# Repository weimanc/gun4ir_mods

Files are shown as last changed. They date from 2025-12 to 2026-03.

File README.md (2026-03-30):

# My GUN4IR blog and mods

## Table of Contents

- [Trigger switch and Recoil](#trigger-switch-and-recoil)
- [Wiimote Sensor and Lens](#wiimote-sensor-and-lens)
- [USB Hub and Power](#usb-hub-and-power)
  - [USB over CAT](#usb-over-cat)
  - [Custom hub](#custom-hub)
    - [RJ45 Pinout](#rj45-pinout)
  - [GUN4IR logo](#gun4ir-logo)
  - [Future ideas](#future-ideas)
- [Bill of materials](#bill-of-materials)
- [Credits and references](#credits-and-references)

I've modified two GunCon1 controllers for my GUN4IR build.

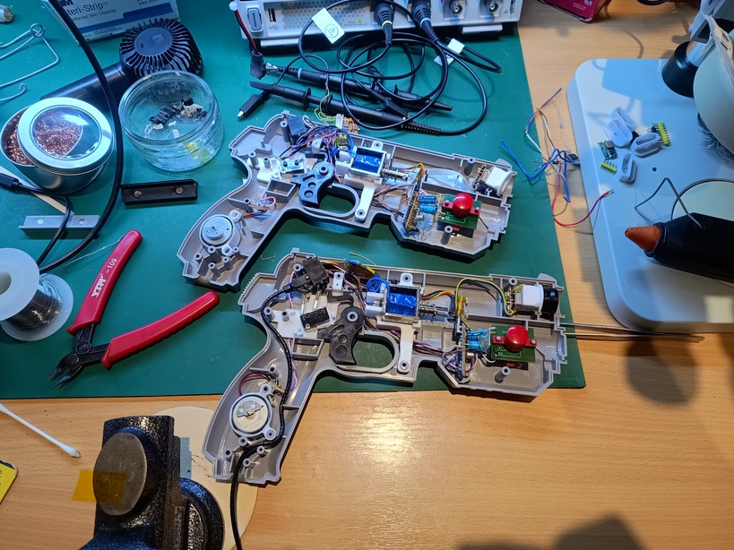
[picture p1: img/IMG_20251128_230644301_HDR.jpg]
My two GunCon1 controllers


# Trigger switch and Recoil

TODO

# Wiimote Sensor and Lens

TODO

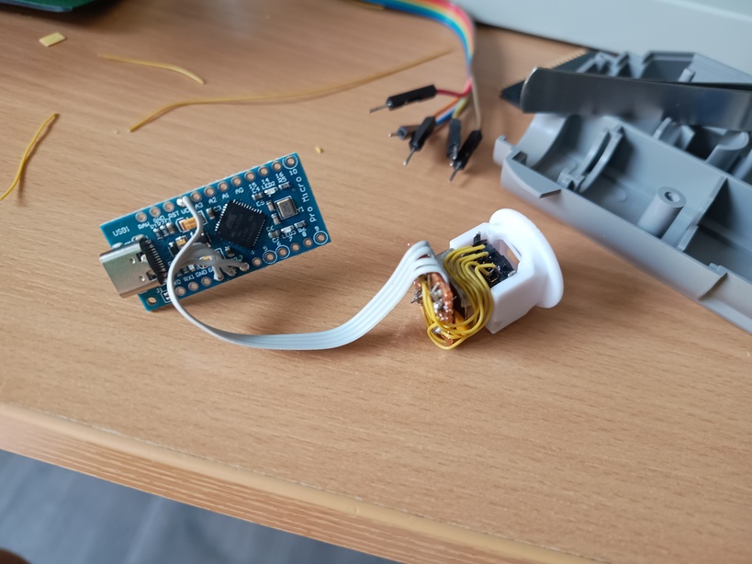
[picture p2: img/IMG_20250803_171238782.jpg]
Extracted Wiimote sensor on a breakout board


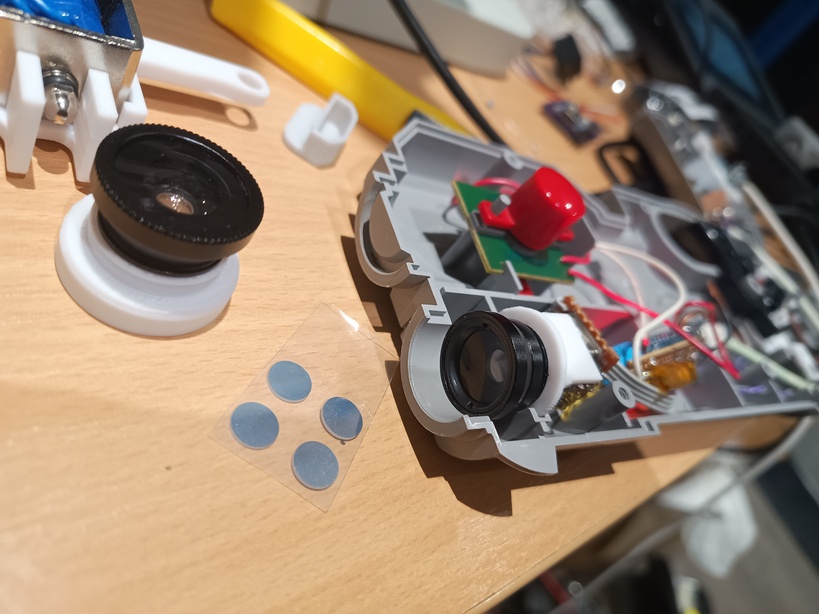
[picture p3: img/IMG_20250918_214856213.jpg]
IR filter and micro lens squeezed in the housing


# USB Hub and Power

I didn't like the idea of having two wires coming out of the GunCon1 — one for USB and one for power. I wondered if I could use an Ethernet cable for the controller wire so I could swap cables in the future. Ethernet cable has 8 wires: 4 for USB and 4 for power, which should be sufficient.

With the 24V external power supply I can power other devices. There are USB power modules that support Quick Charge and USB Power Delivery (USB‑PD). This could be used to power a device such as the MiSTer FPGA.
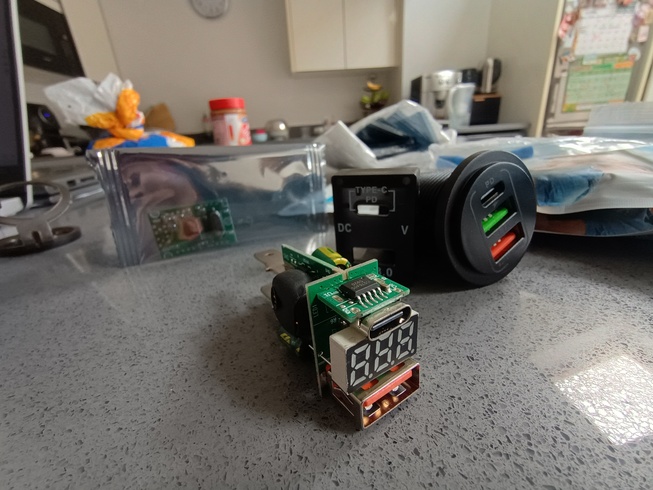
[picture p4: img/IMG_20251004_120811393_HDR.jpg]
USB-PD power module


## USB over CAT

I've read that USB cables are recommended up to 1.2 meters. I had a bad experience extending USB cables for a keyboard and mouse setup, which made me cautious.
I needed to check whether USB would work over Ethernet cable. I made a small prototype and, to my surprise, it did work — even with a 5 m cable!

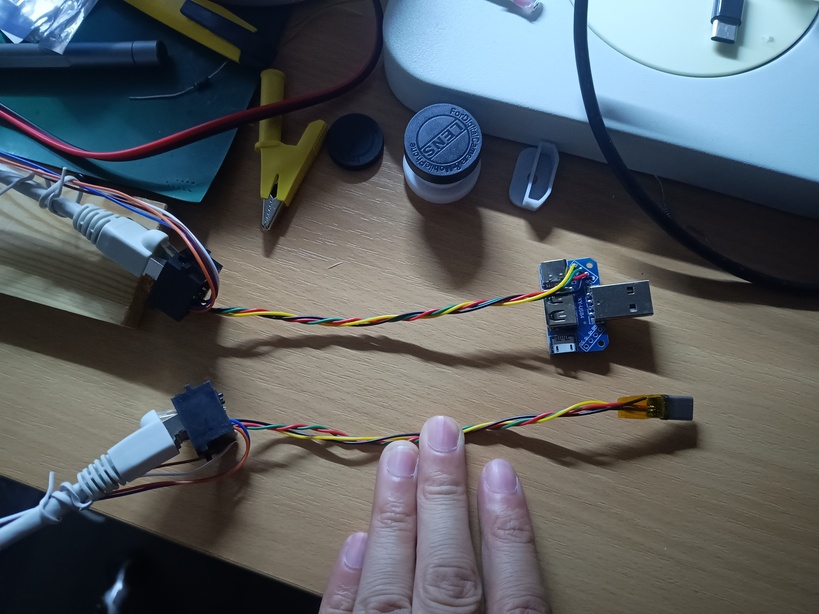
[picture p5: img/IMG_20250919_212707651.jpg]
Testing USB over CAT

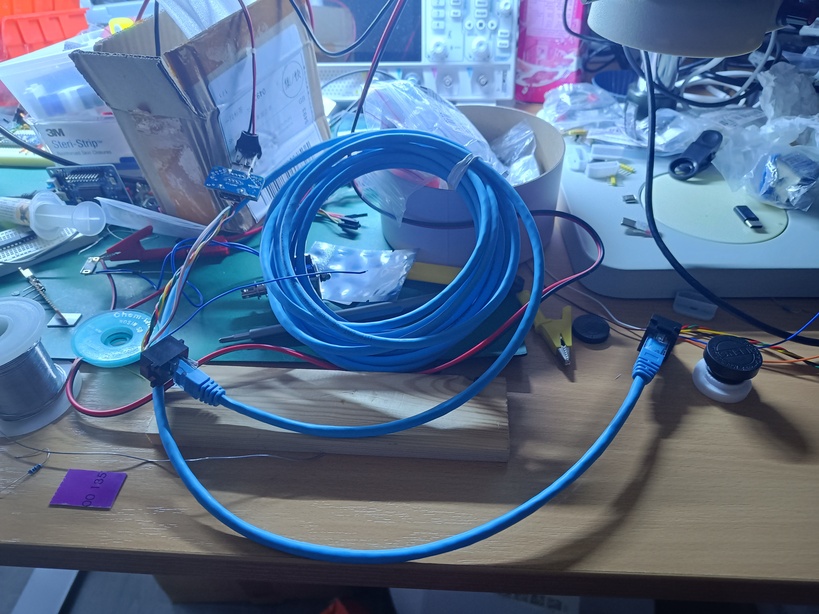
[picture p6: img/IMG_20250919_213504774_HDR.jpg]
Testing with 5 meter Ethernet cable


## Custom hub

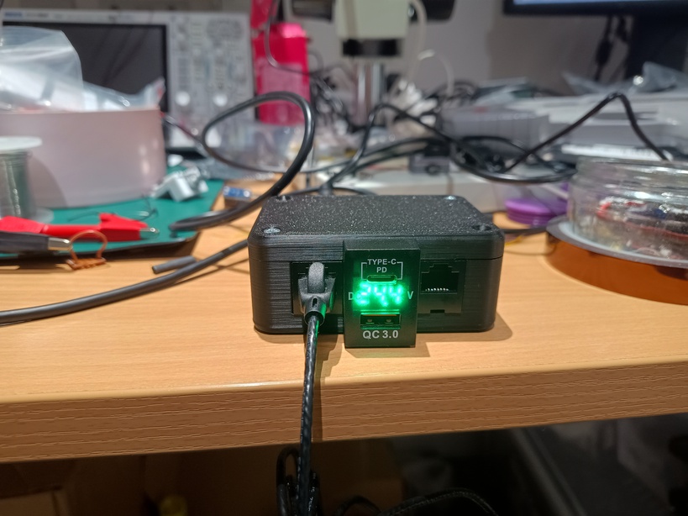
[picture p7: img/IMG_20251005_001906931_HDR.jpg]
GUN4IR custom hub


I want to keep the overall wiring tidy and neat. My plan was to create a custom box to house the USB hub and bring 24V power in to feed the GunCons. On AliExpress I found a PCB-only 4-port USB hub and a 24V power brick, and a 24V-to-USB‑PD power module that could also power my MiSTer FPGA box.

Using Onshape, I've created a simple box with cutouts:

- 2x RJ45 ports
- USB‑PD power out
- USB‑B towards the host
- 24V barrel jack power in
- Power switch

To my surprise, I got all dimensions right, I didn't need to reprint. Some of the connects (DC and USB-B) have a very tight fit.
Wiring is straightforward. I did, however, burn out a USB hub due to incorrect USB wiring. This was caused by a Google search that returned an image with the wrong USB‑B pinout.

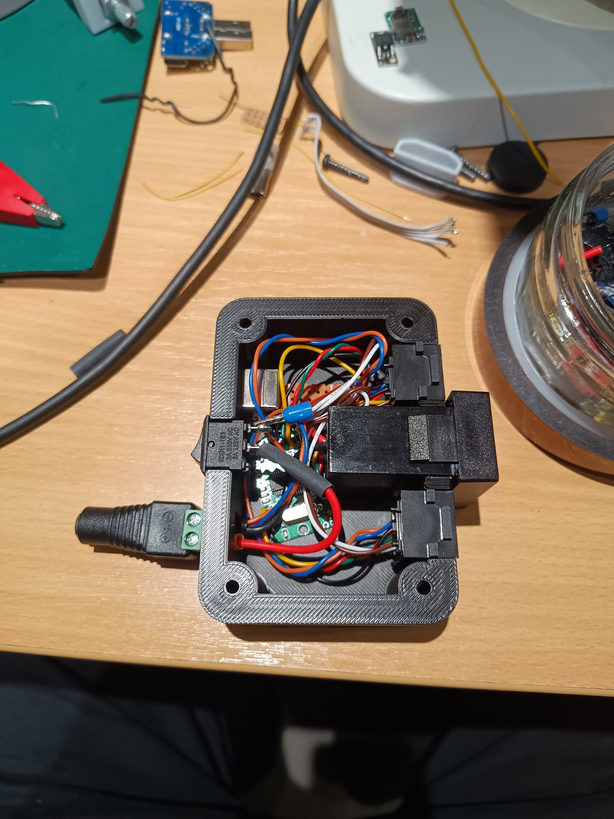
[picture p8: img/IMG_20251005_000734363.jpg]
Wiring inside my custom hub


### RJ45 Pinout

Look for "641D 8P" in AliExpress. This is a nice wired modular jack 8P8C assembly, compatible to accept network etherne wires. The twisted pairs are being use hoping that the USB datapair will benefit from this. The 24V is making use of 4 wires. This is the pinout used:

| 641D 8P Connector | RJ45 Pin | RJ45 T-568B  | Function |
| --- | --- | --- | --- |
| Yellow | 6 | Green | USB VCC |
| Black | 3 | Green/White  | USB GND |
| Red | 4 | Blue | USB D+ |
| Green | 5 | Blue/White | USB D- |
| White | 8 | Brown | Solenoid 24V |
| Brown | 7 | Brown/White  | Solenoid 24V |
| Orange | 2 | Orange | Solenoid 0V  |
| Blue | 1 | Orange/White | Solenoid 0V  |

## GUN4IR logo

The hub looked boring and needed some flare. I thought the GUN4IR logo would look awesome and asked JayBee for his blessing. He provided me a STEP file, which helped the CAD work.

[click for printing instructions](INSTRUCTIONS_LOGO.md)

## Future ideas

There are a few ideas I have for this hub that would be cool. The USB hub is a 4 port hub. So with 2 GunCon ports, I have two unused ports:

- expose unused USB ports
- built-in USB storage
- a gamepad as the case top — this could make a really cute controller!

# Bill of materials

# Credits and references

## Onshape

[My GUN4IR Onshape project](https://cad.onshape.com/documents/60f3889d38b5e0568d106ee2/w/f5cb8cd99e0bbe5bb5cbe4ad/e/dea12f17ca6bb715148ab42e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)

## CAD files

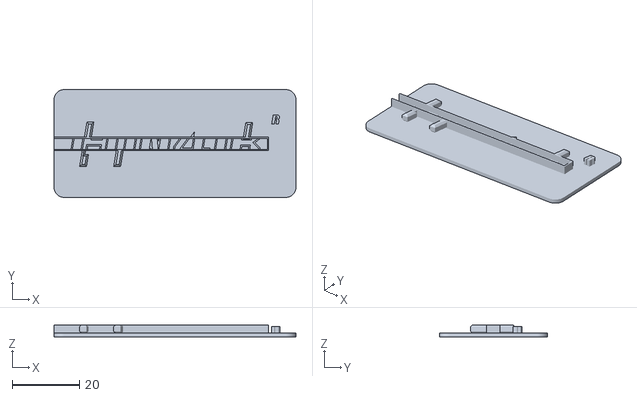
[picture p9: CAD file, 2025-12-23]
stl/hub24v_case - base.stl
71.8 x 32.0 x 3.70

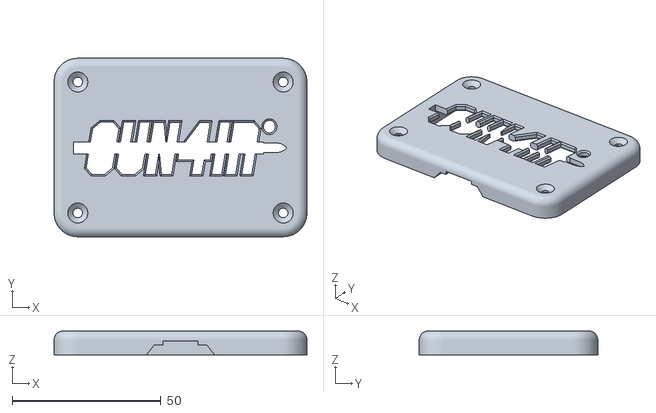
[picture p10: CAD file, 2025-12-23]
stl/hub24v_case - cover.stl
85.0 x 60.0 x 8.05

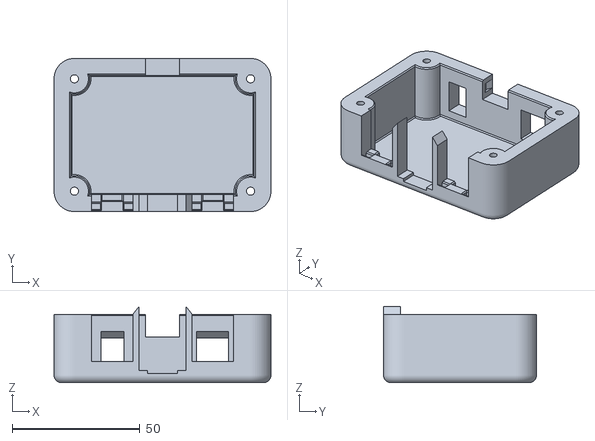
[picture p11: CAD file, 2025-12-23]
stl/hub24v_case - case.stl
85.0 x 60.0 x 29.9

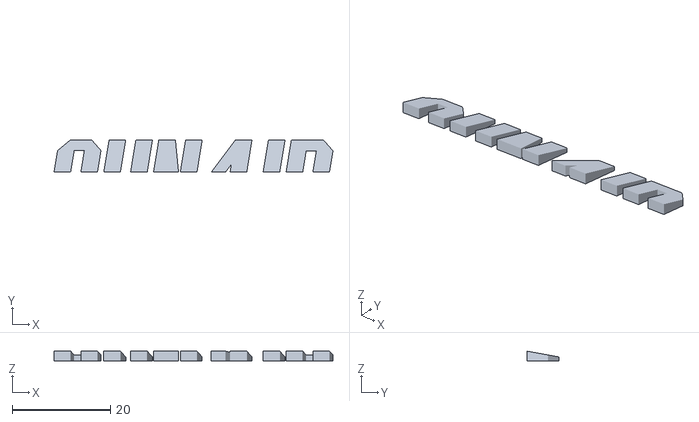
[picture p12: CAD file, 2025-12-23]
stl/hub24v_case - letters upper.stl
56.7 x 6.59 x 2.00

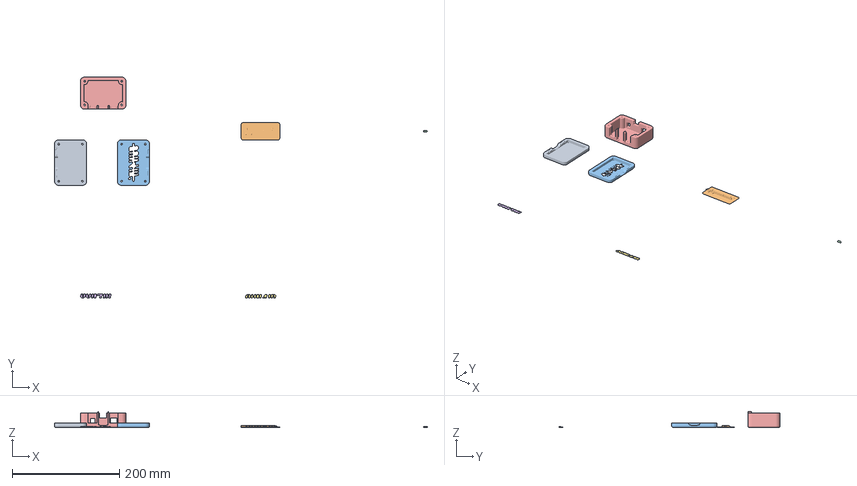
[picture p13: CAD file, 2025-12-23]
stl/hub24v_case.3mf
694.9 x 411.7 x 29.9 mm
hub24v_case - Part 1.stl
hub24v_case - base.stl
hub24v_case - cover.stl
hub24v_case - bullet.stl
hub24v_case - Part 2.stl
hub24v_case - letters lower.stl
hub24v_case - letters upper.stl

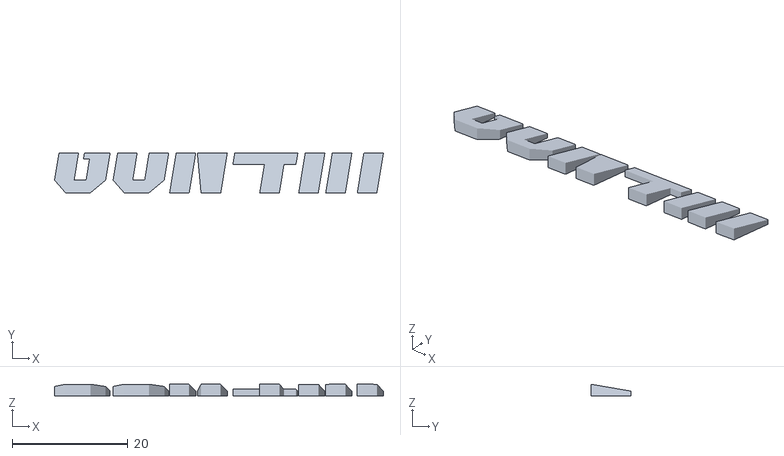
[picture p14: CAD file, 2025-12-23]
stl/hub24v_case - letters lower.stl
56.8 x 6.98 x 2.00

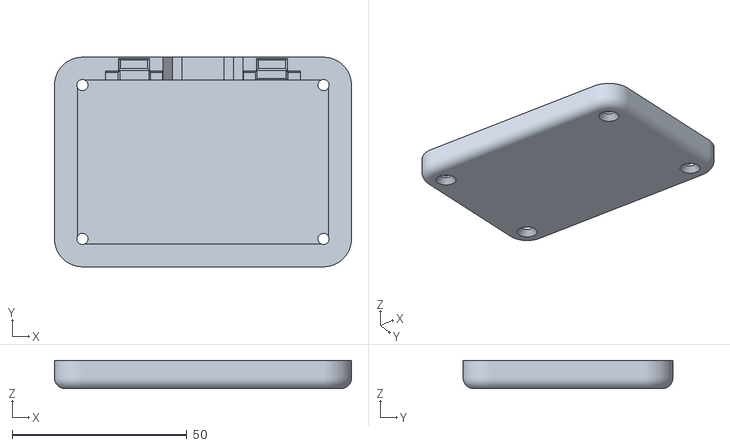
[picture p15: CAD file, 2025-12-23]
stl/hub24v_case - cover_blank.stl
85.0 x 60.0 x 8.05

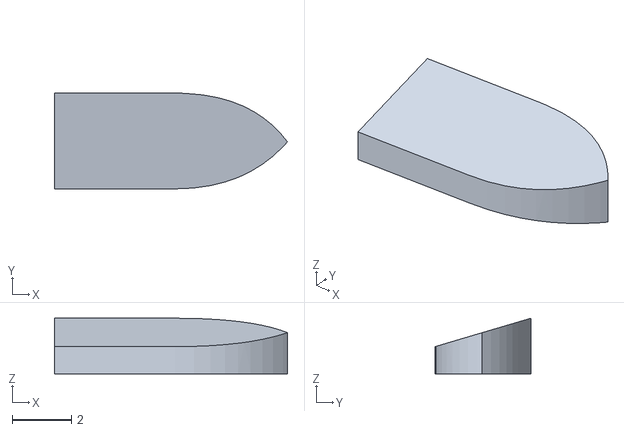
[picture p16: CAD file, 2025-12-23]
stl/hub24v_case - bullet.stl
7.89 x 3.24 x 1.88

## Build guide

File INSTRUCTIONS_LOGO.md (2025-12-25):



# GUN4IR Logo

3D printing is amazing — you can print custom cases with ease. I have a Bambu P1S with AMS. I don't do many multi‑colour prints because the purging (printer "poop") is very wasteful. I like to challenge myself by limiting to a maximum of one colour swap per print. I try to skip or reduce purging and experiment with mixing two colours so the blend becomes a feature.

The GUN4IR logo uses four colours: red, blue, white, and black. The logo features colour gradients in discrete steps, which reminded me of the stair-step effect when printing a slope (z-height relative to layer thickness). The idea is to use the more translucent colour to build up the slope and create the colour change.

I count five bands for the colour gradient. Using a layer height of 0.2 mm, the slope height is (5 + 1) * 0.2 = 1.2 mm — the extra +1 is a margin to allow for slicer behaviour.

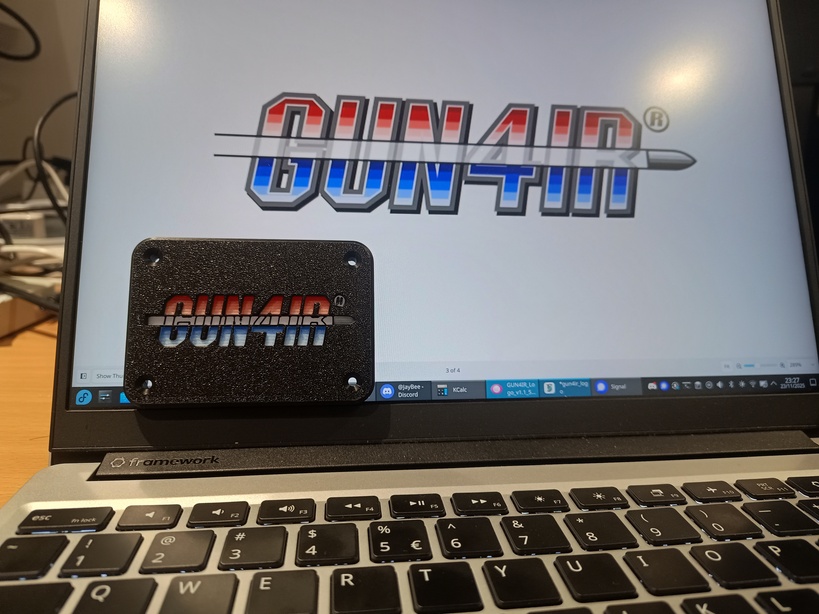
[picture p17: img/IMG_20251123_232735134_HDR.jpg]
Printed case top vs GUN4IR logo


# Printing instructions

Global settings

- Layer height: 0.2 mm
- Detect thin walls
- Disable prime tower

The GUN4IR logo consists of five parts.

| Part | Colour 1 | Colour 2 | Swap layer | Flushing volume multiplier | Brim |
| --- | --- | --- | --- | --- | ---- |
| cover | black | | | | |
| base | white | black | 7 | 0.70 | |
| bullet | black | white | 6 | 0.70 | 3 mm |
| letters lower  | blue | white | 5 | 0.15 | 3 mm |
| letters upper  | red | white | 5 | 0.15 | 3 mm |

For the red→white and blue→white transitions, you can get away with a reduced flushing volume. For black↔white you do need to purge the extruder properly. I set the global multiplier to 0.15 but restored the black↔white parameters to their default values. In theory you could use these flushing volume settings:

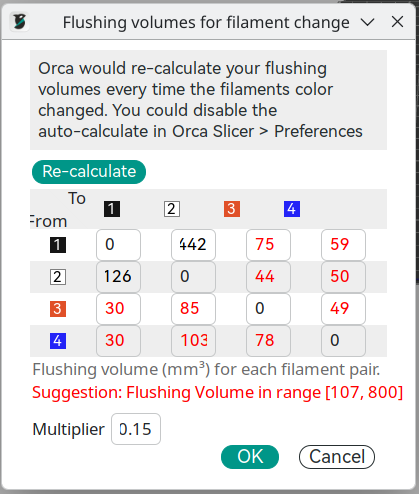
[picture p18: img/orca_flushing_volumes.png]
Flushing volume settings in OrcaSlicer


# Assembly instructions

The bullet and letters are printed with a brim. This helps keep the letter parts together and also aids alignment with the base. Some trimming of the brim is needed to make the letters fit.

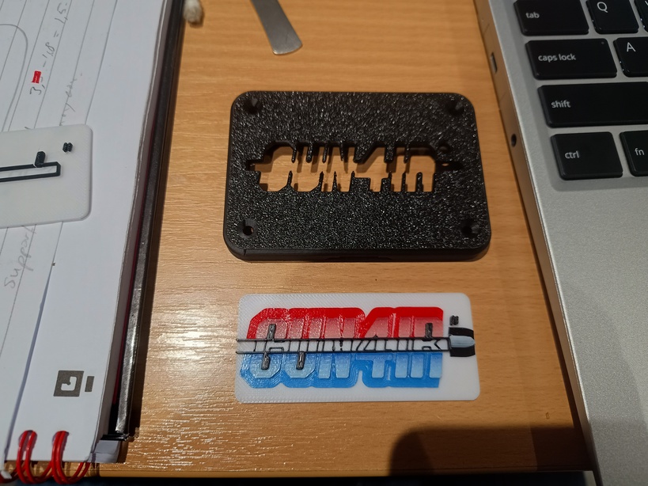
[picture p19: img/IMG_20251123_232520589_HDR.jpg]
Prepare the insert


The base can then be pressed into the top cover.

You can use superglue to bond the parts.

The design is made without clearance; the parts are small and thin enough that they will flex into place. Your mileage may vary depending on your printer.

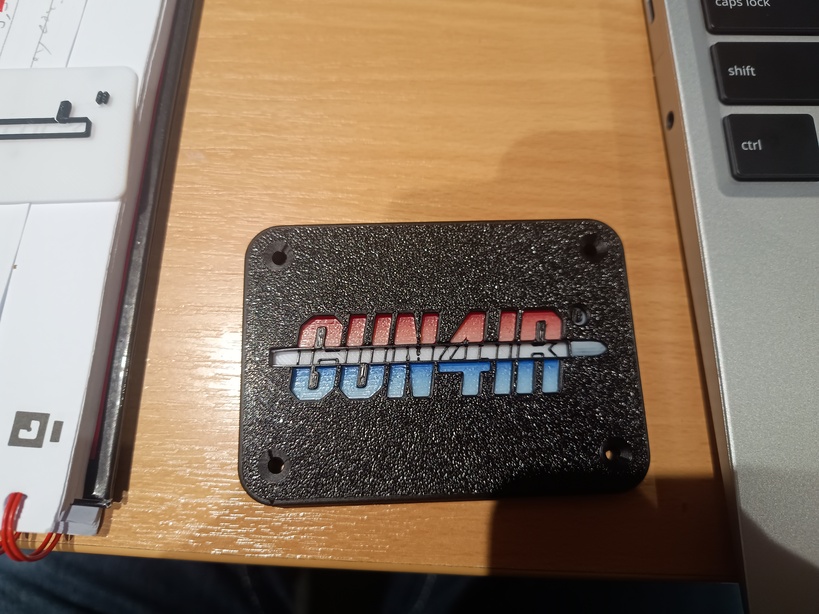
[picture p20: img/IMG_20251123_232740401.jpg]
Printed case top


[← Back to GUN4IR Mods](README.md)
